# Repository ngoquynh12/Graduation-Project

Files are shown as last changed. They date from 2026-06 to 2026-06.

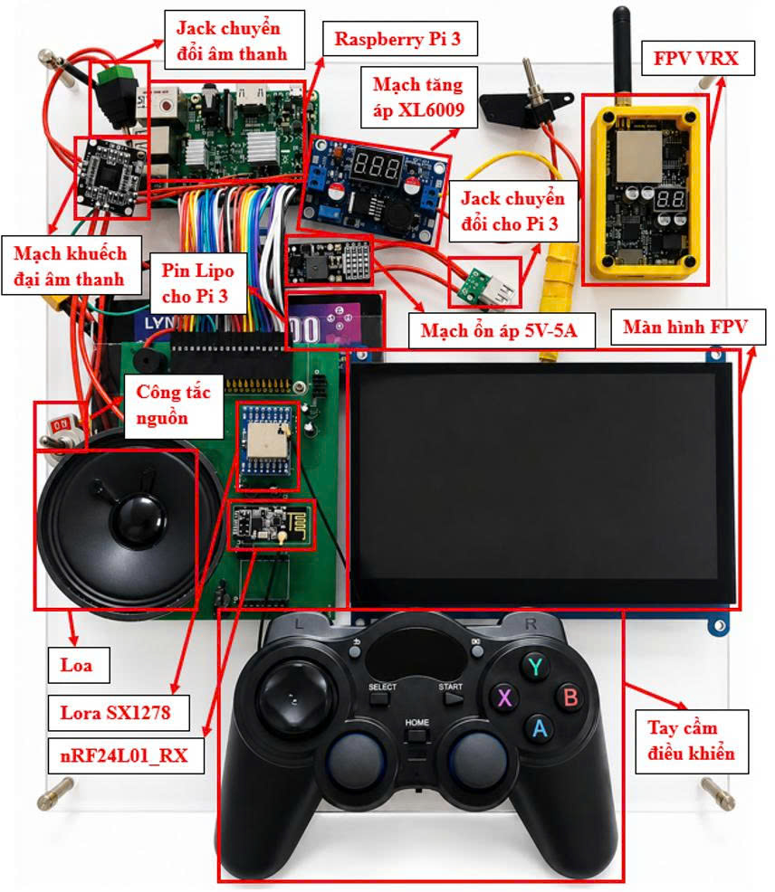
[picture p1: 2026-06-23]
PICTURES/control_station.jpg

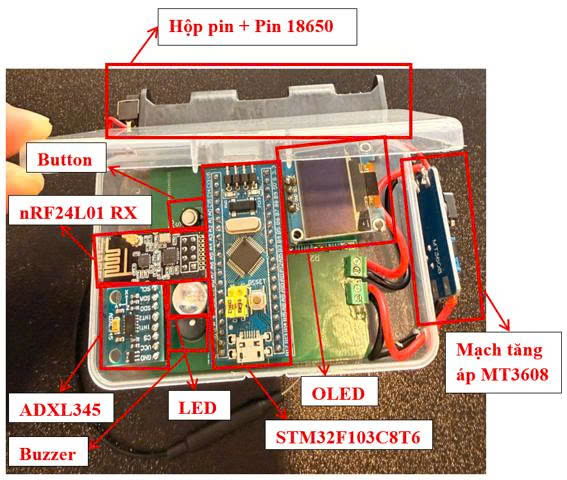
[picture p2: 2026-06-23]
PICTURES/marker.jpg

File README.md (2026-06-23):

# Design and Implementation of an AI-Powered Multi-Sensor Hexapod Robot for Earthquake Search and Rescue

## Overview

This project presents the design and implementation of an AI-powered multi-sensor hexapod robot for earthquake search and rescue applications.

The robot is designed to operate in complex and hazardous environments where direct human access may be dangerous. The system integrates computer vision, audio intelligence, vibration monitoring, wireless communication, FPV monitoring, and autonomous navigation through a multi-sensor fusion architecture.

By combining artificial intelligence, embedded systems, wireless communication, and a six-legged locomotion platform, the robot assists rescue teams in locating potential victims, monitoring disaster areas, and improving situational awareness during emergency operations.

This project was developed as a Graduation Thesis at Ho Chi Minh City University of Technology (HCMUT), Vietnam National University Ho Chi Minh City.

---

## Project Objectives
- Develop a hexapod robot capable of traversing rough terrain.
- Detect humans and animals using AI-based image recognition.
- Detect human and animal sounds using AI-based audio classification.
- Monitor post-earthquake vibrations and aftershocks.
- Support both manual and autonomous operation modes.
- Deploy rescue markers at suspected victim locations.
- Transmit real-time information to a remote control station.
- Provide live FPV video streaming and system monitoring dashboard.

---

## System Architecture

### Robot Platform
- Hexapod structure with 18 DOF.
- Tripod gait locomotion.
- Manual and autonomous navigation modes.
- Obstacle avoidance using distance sensors.

### AI Vision System
- Raspberry Pi 5.
- Raspberry Pi Camera V2.
- YOLOv8 object detection.
- Detection classes: Person, Dog and Cat.

### AI Audio System
- INMP441 I2S Microphone.
- CNN-based audio classification.
- Detection classes: Human voice, Dog bark and Environmental noise.

### Vibration Monitoring
- MPU6050 Accelerometer.
- PGA (Peak Ground Acceleration) calculation.
- MMI (Modified Mercalli Intensity) estimation.
- Aftershock monitoring.

### Wireless Communication
- LoRa SX1278.
- nRF24L01.
- Real-time sensor transmission.
- Remote command and control.

### FPV Monitoring
- FPV Camera.
- 5.8 GHz Video Transmission.
- Real-time video feedback to operator.

### Rescue Marker System
- Marker deployment mechanism.
- Wireless status reporting.
- Rescue state monitoring.

### Web Dashboard
- Real-time sensor monitoring.
- Robot status visualization.
- Marker tracking.
- Alert notifications.

### Ground Control Station
- Real-time dashboard.
- Sensor monitoring.
- Marker tracking.
- Audio alerts.
- Robot telemetry display.

---

## Technologies Used

### Main Hardware
- Raspberry Pi 5 (Main Robot Controller).
- Raspberry Pi 3 (Ground Control Station).
- Raspberry Pi Camera V2.
- INMP441 Microphone.
- MPU6050.
- LoRa SX1278.
- nRF24L01.
- PCA9685 Servo Driver.
- MG946R Servo Motors.
- FPV Camera System.

### Software
- Python.
- YOLOv8.
- TensorFlow / Keras.
- OpenCV.
- Flask.
- HTML / CSS / JavaScript.

### PCB Design
- Altium Designer.

### Mechanical Design
- CAD Modeling.
- 3D Printed Components.

---

## Demo Videos
YouTube Playlist: https://www.youtube.com/playlist?list=PLQ2nYnHPs12wPHYRxYziXRSKi9JFzzbWc

The playlist includes:
- Hexapod locomotion testing.
- Manual control mode.
- Autonomous navigation mode.
- Obstacle avoidance.
- Human detection.
- Audio detection.
- Marker deployment.
- Dashboard monitoring.
- System integration tests.

---

## Results
The developed system successfully demonstrates:
- Stable hexapod locomotion.
- Real-time AI-based human and animal detection.
- AI-based audio recognition.
- Obstacle avoidance capability.
- Aftershock monitoring.
- Wireless communication between robot and control station.
- Rescue marker deployment.
- FPV video transmission.
- Real-time dashboard monitoring.

The integration of AI, embedded systems, wireless communication and multi-sensor fusion improves situational awareness and supports search-and-rescue operations in hazardous environments.

---

## Authors
Ngô Diễm Quỳnh – 2212887

Nguyễn Trọng Tuấn – 2213794

Department of Electronics and Telecommunications Engineering

Ho Chi Minh City University of Technology (HCMUT)

Vietnam National University Ho Chi Minh City

Supervisor: TS. Nguyễn Lý Thiên Trường

---

## License

This repository is published for academic and portfolio purposes.
Please contact the authors before using the materials for commercial applications.

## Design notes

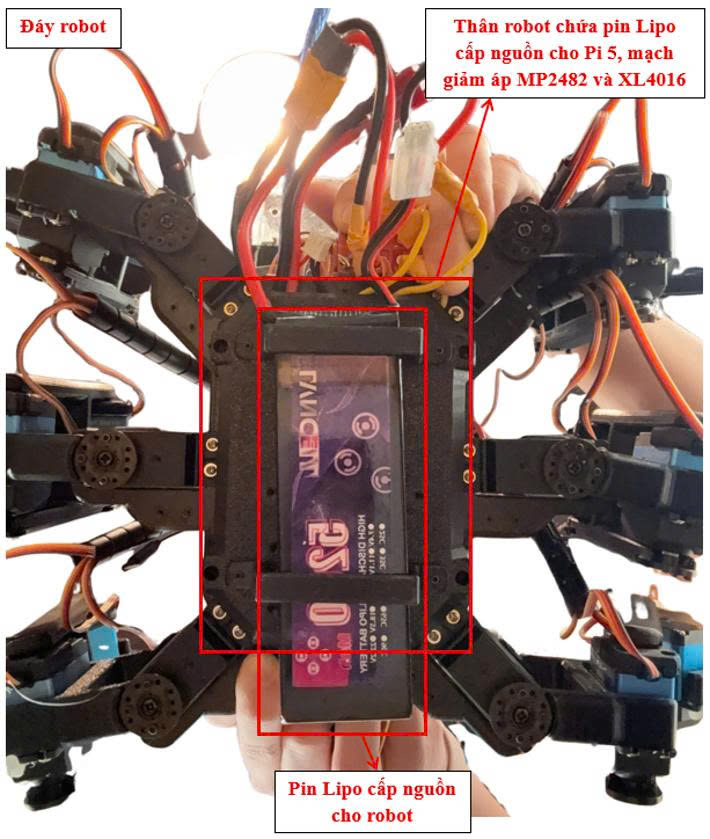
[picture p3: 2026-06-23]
PICTURES/robot_bottom.jpg

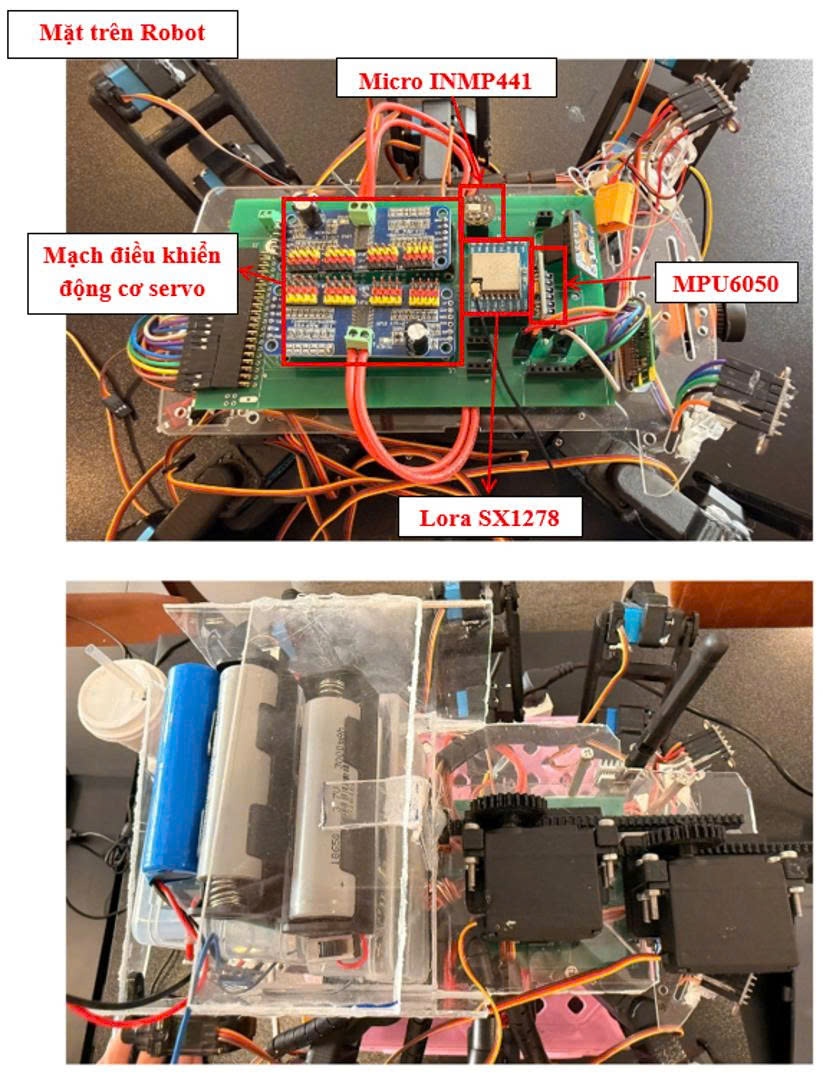
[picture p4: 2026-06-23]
PICTURES/robot_above.jpg

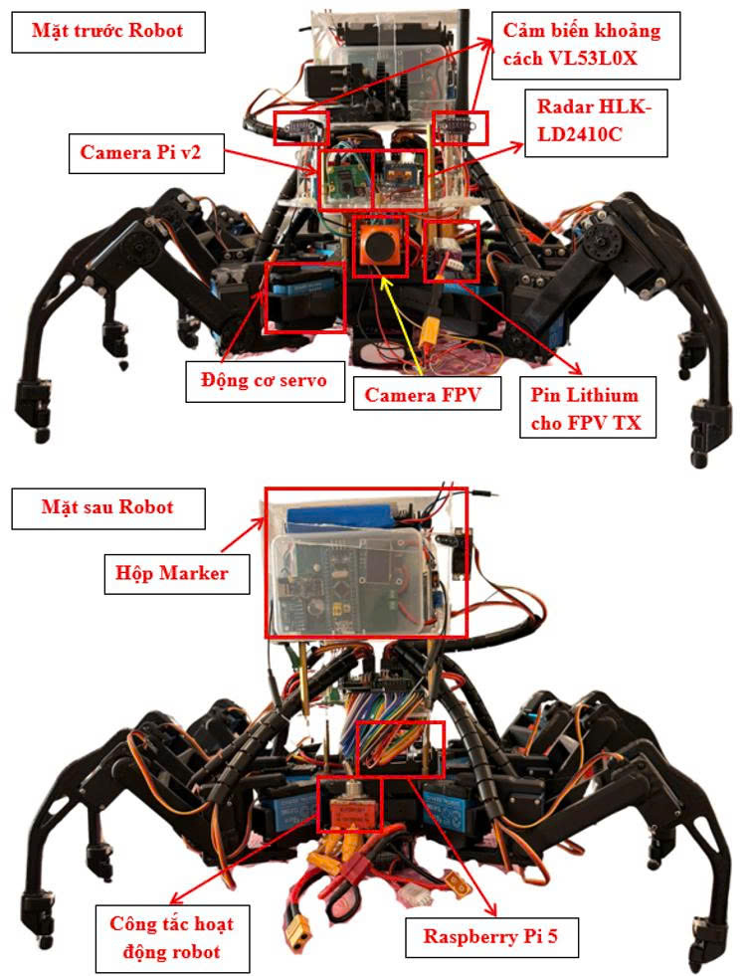
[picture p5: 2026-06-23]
PICTURES/robot_front.jpg

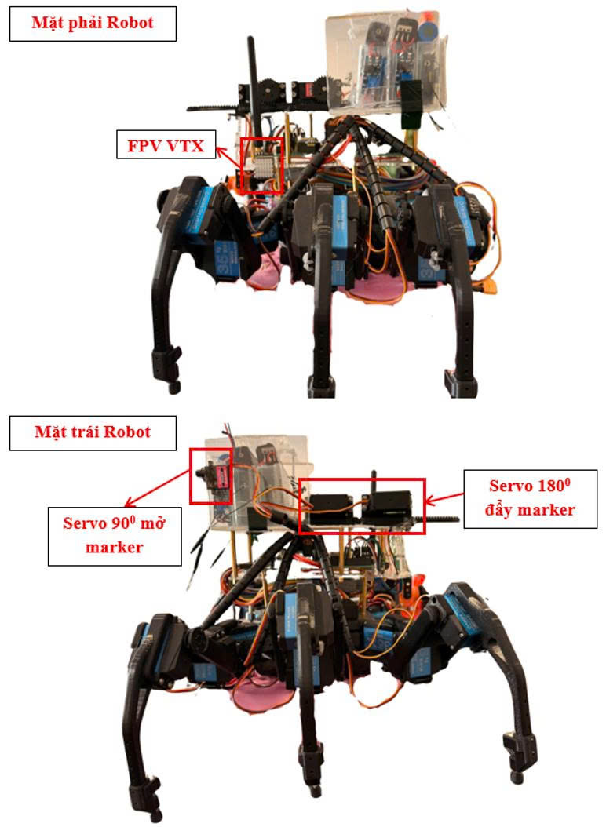
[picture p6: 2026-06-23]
PICTURES/robot_side.jpg

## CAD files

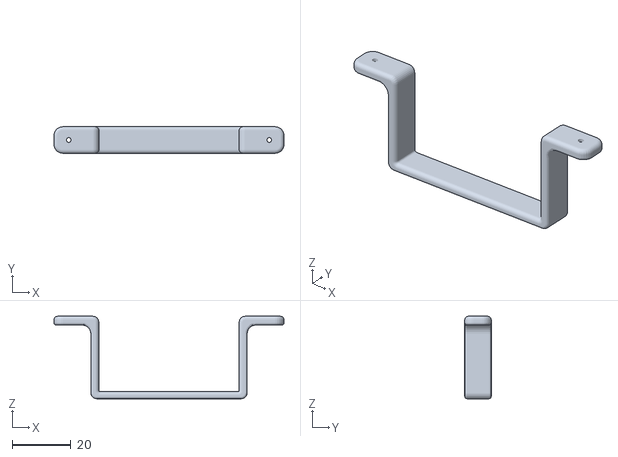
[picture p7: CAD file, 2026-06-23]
Mechanical/battery-bar.stl
78.0 x 9.00 x 28.0

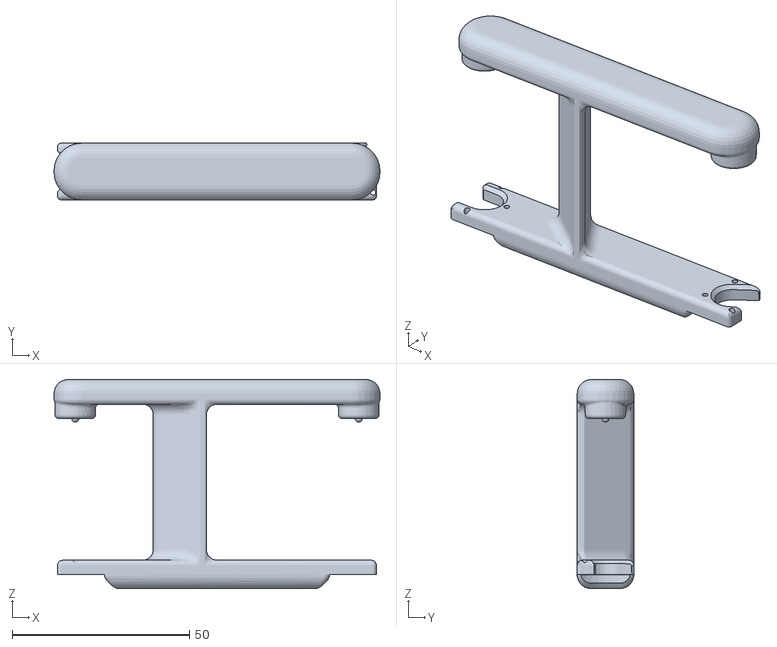
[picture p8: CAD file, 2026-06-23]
Mechanical/right-femur.stl
92.0 x 16.0 x 59.0

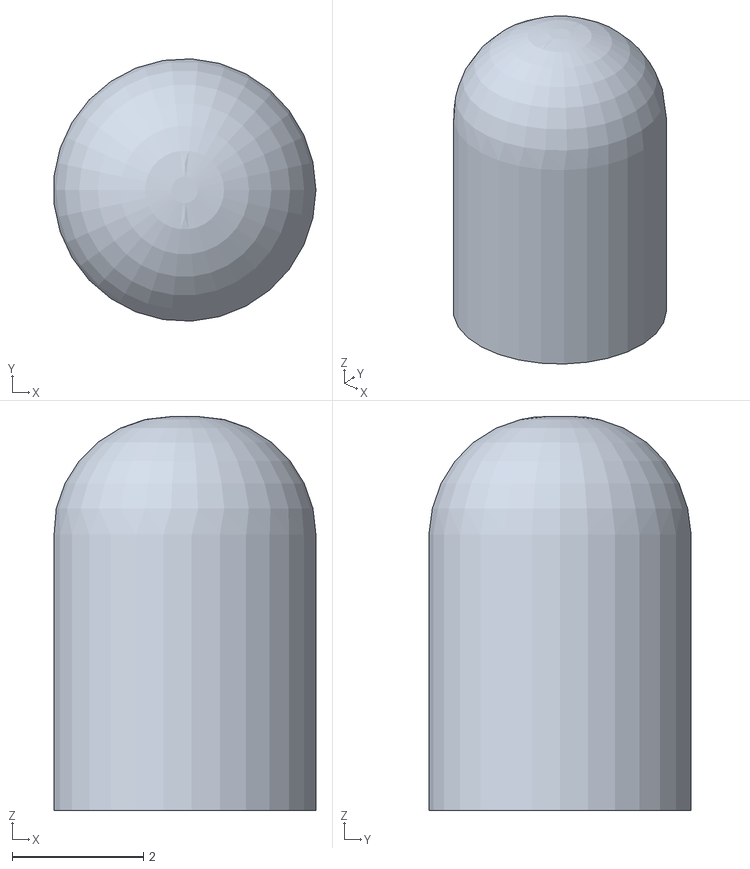
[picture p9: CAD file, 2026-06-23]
Mechanical/limiter.stl
3.99 x 3.99 x 6.00

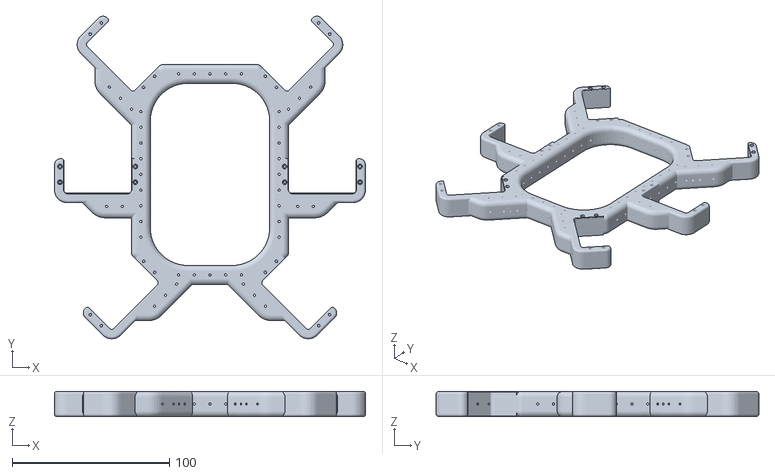
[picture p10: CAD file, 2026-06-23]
Mechanical/frame.stl
198.0 x 205.4 x 16.0

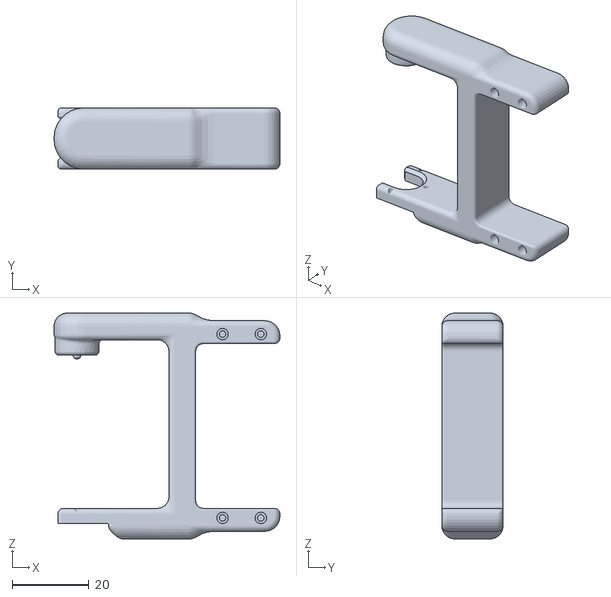
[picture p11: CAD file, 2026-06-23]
Mechanical/right-coxa.stl
59.0 x 16.0 x 59.0

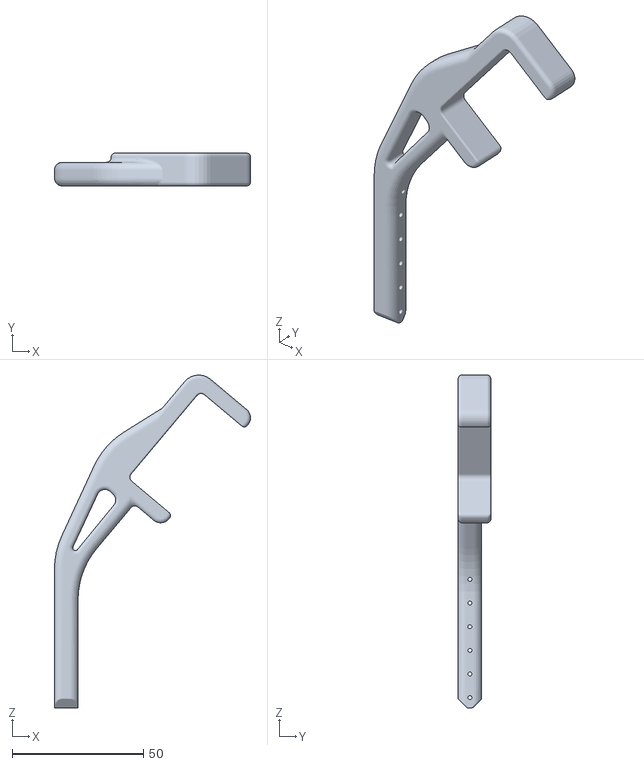
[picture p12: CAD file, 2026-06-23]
Mechanical/right-tibia.stl
74.6 x 12.5 x 126.7

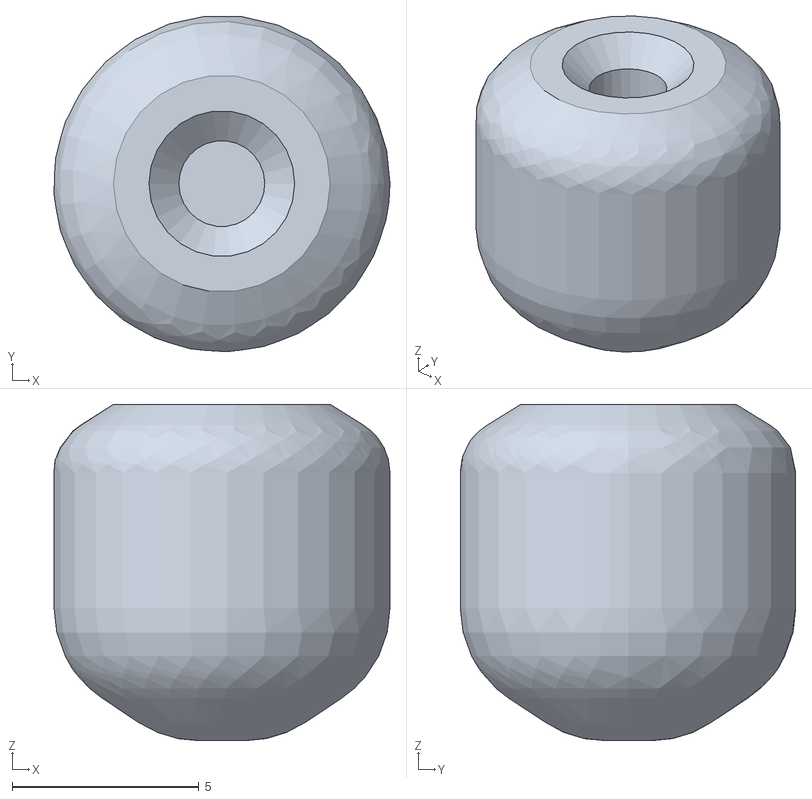
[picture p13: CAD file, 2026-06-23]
Mechanical/tip.stl
8.99 x 8.98 x 9.00

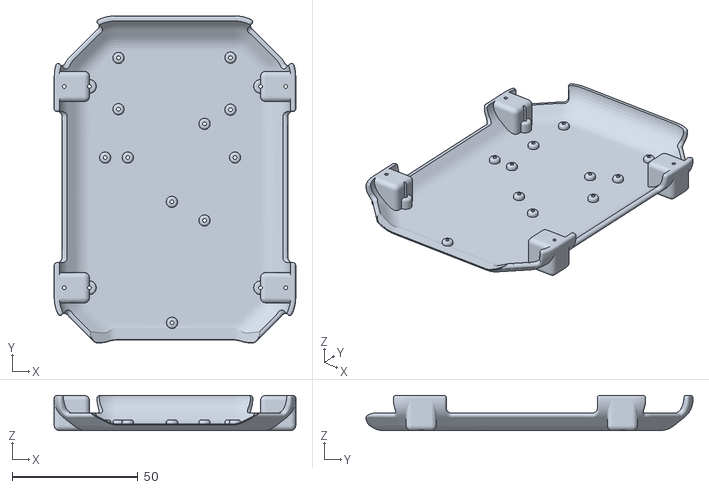
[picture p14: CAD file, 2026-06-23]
Mechanical/bottom-cover.stl
96.0 x 130.0 x 14.0

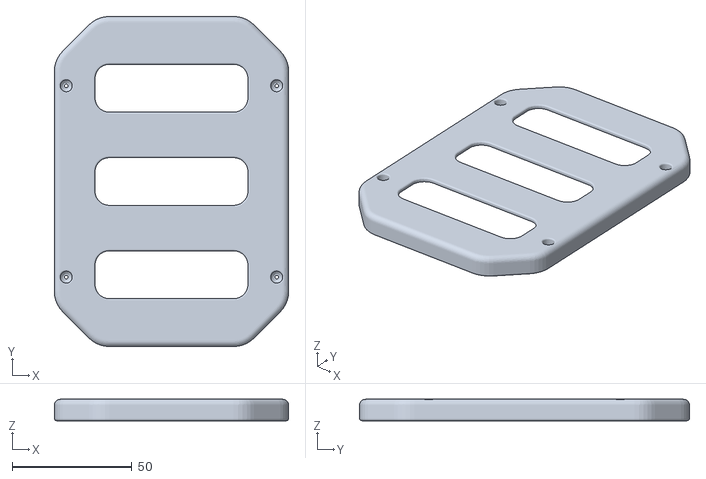
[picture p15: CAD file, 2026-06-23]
Mechanical/top-cover.stl
98.0 x 138.0 x 9.00

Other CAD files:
Mechanical/left-femur.stl
Mechanical/left-tibia.stl
Mechanical/left-coxa.stl

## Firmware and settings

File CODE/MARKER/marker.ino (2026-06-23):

#include <Wire.h>
#include <SPI.h>
#include <RF24.h>
#include <Adafruit_GFX.h>
#include <Adafruit_SSD1306.h>
#include <math.h>

// ================= OLED =================
#define SCREEN_WIDTH 128
#define SCREEN_HEIGHT 64
#define OLED_RESET -1
#define OLED_ADDR 0x3C
Adafruit_SSD1306 display(SCREEN_WIDTH, SCREEN_HEIGHT, &Wire, OLED_RESET);

// ================= ADXL345 (I2C2) =================
#define ADXL_ADDR 0x53
TwoWire I2C_ADXL(PB11, PB10);   // SDA, SCL

// ================= PIN =================
#define LED_PIN       PB0
#define BUZZER_PIN    PB1
#define BUTTON_PIN    PA0
#define BATTERY_PIN   PA2

#define NRF_CE_PIN    PA3
#define NRF_CSN_PIN   PA4

// ================= RF24 =================
RF24 radio(NRF_CE_PIN, NRF_CSN_PIN);
const byte address[6] = "MKR01";

// ================= CONFIG =================
const uint8_t MARKER_ID = 1;

uint8_t markerStatus = 0;

bool ledState = false;
bool radioAvailable = false;
bool lastSendResult = false;
bool adxlAvailable = false;
bool isSleeping = false;

unsigned long previousLedMillis = 0;
unsigned long previousDisplayMillis = 0;
unsigned long previousSendMillis = 0;
unsigned long previousBatteryMillis = 0;
unsigned long lastDebounceTime = 0;
unsigned long bootTime = 0;
unsigned long lastImpactMillis = 0;
unsigned long rescuedTime = 0;

bool lastButtonReading = HIGH;
bool buttonState = HIGH;

const unsigned long ledInterval = 500;
const unsigned long displayInterval = 200;
const unsigned long sendInterval = 1000;
const unsigned long batteryUpdateInterval = 250;
const unsigned long debounceDelay = 50;
const unsigned long impactCooldown = 1500;
const unsigned long rescuedToSleepDelay = 2000;

// double click
int clickCount = 0;
unsigned long lastClickTime = 0;
const unsigned long doubleClickWindow = 400;

// impact detect
int impactCount = 0;
const long impactDeltaThreshold = 520;
const int impactNeedCount = 4;

long baseMagnitude = 0;
bool baseReady = false;

// ================= BATTERY =================
float batteryVoltageShown = -1.0f;
float batteryVoltageRaw = -1.0f;
float batteryVoltageFiltered = -1.0f;

const float batteryCalibrationFactor = 0.001607f;

// chỉnh cho OLED cập nhật tụt áp nhanh hơn
const float batteryTinyDeadband = 0.002f;
const float maxBatteryDropPerUpdate = 0.080f;
const float maxBatteryRisePerUpdate = 0.020f;

// ================= BUZZER =================
const unsigned long buzzerCycle = 2000;

const unsigned long beep1Start = 0;
const unsigned long beep1End   = 150;

const unsigned long beep2Start = 300;
const unsigned long beep2End   = 450;

const unsigned long beep3Start = 600;
const unsigned long beep3End   = 750;

const int freq1 = 2500;
const int freq2 = 3000;
const int freq3 = 3500;

// ================= RF PAYLOAD =================
struct __attribute__((packed)) MarkerPacket {
  uint8_t id;
  uint8_t status;
  float battery;
  uint32_t counter;
};

MarkerPacket packet;
uint32_t packetCounter = 0;

// ================= ADXL DATA =================
int16_t ax = 0, ay = 0, az = 0;

// ================= FORWARD DECLARATIONS =================
void sendMarkerPacket(float batteryVoltage);
void enterSleepMode();
void wakeFromSleep();
bool isBuzzerActive(unsigned long currentMillis);

// ================= HELPER =================
const char* getStatusText(uint8_t st) {
  if (st == 0) return "WAITING";
  if (st == 1) return "NOT RESCUED";
  if (st == 2) return "RESCUED";
  return "UNKNOWN";
}

// ================= ADXL345 =================
void adxlWrite(uint8_t reg, uint8_t value) {
  I2C_ADXL.beginTransmission(ADXL_ADDR);
  I2C_ADXL.write(reg);
  I2C_ADXL.write(value);
  I2C_ADXL.endTransmission();
}

bool adxlReadXYZ(int16_t &x, int16_t &y, int16_t &z) {
  I2C_ADXL.beginTransmission(ADXL_ADDR);
  I2C_ADXL.write(0x32);
  if (I2C_ADXL.endTransmission(false) != 0) return false;

  I2C_ADXL.requestFrom(ADXL_ADDR, 6);
  if (I2C_ADXL.available() < 6) return false;

  x = I2C_ADXL.read() | (I2C_ADXL.read() << 8);
  y = I2C_ADXL.read() | (I2C_ADXL.read() << 8);
  z = I2C_ADXL.read() | (I2C_ADXL.read() << 8);

  return true;
}

bool initADXL345() {
  I2C_ADXL.begin();

  adxlWrite(0x2D, 0x08);
  adxlWrite(0x31, 0x0B);

  delay(20);

  int16_t tx, ty, tz;
  return adxlReadXYZ(tx, ty, tz);
}

void adxlSleep() {
  if (!adxlAvailable) return;
  adxlWrite(0x2D, 0x00);
}

void adxlWake() {
  if (!adxlAvailable) return;
  adxlWrite(0x2D, 0x08);
  delay(10);
}

// ================= BATTERY =================
float readBatteryBlockTrimmedMean(int sampleCount, int adcDelayMs) {
  if (sampleCount < 5) sampleCount = 5;

  int buf[80];
  if (sampleCount > 80) sampleCount = 80;

  for (int i = 0; i < sampleCount; i++) {
    buf[i] = analogRead(BATTERY_PIN);
    delay(adcDelayMs);
  }

  for (int i = 0; i < sampleCount - 1; i++) {
    for (int j = i + 1; j < sampleCount; j++) {
      if (buf[j] < buf[i]) {
        int t = buf[i];
        buf[i] = buf[j];
        buf[j] = t;
      }
    }
  }

  int cut = sampleCount / 5;
  if (cut < 1) cut = 1;
  if (cut * 2 >= sampleCount) cut = 1;

  long sum = 0;
  int count = 0;

  for (int i = cut; i < sampleCount - cut; i++) {
    sum += buf[i];
    count++;
  }

  float rawAvg = sum / (float)count;
  return rawAvg * batteryCalibrationFactor;
}

float readBatteryVoltageStableSnapshot() {
  const int rounds = 7;
  float values[rounds];

  for (int r = 0; r < rounds; r++) {
    values[r] = readBatteryBlockTrimmedMean(25, 2);
    delay(12);
  }

  for (int i = 0; i < rounds - 1; i++) {
    for (int j = i + 1; j < rounds; j++) {
      if (values[j] < values[i]) {
        float t = values[i];
        values[i] = values[j];
        values[j] = t;
      }
    }
  }

  return values[rounds / 2];
}

void initBatteryFilter() {
  float v = readBatteryVoltageStableSnapshot();
  batteryVoltageRaw = v;
  batteryVoltageFiltered = v;
  batteryVoltageShown = v;
}

bool isBuzzerActive(unsigned long currentMillis) {
  if (isSleeping || markerStatus != 1) return false;

  unsigned long phase = currentMillis % buzzerCycle;

  return ((phase >= beep1Start && phase < beep1End) ||
          (phase >= beep2Start && phase < beep2End) ||
          (phase >= beep3Start && phase < beep3End));
}

void updateBatteryShown(unsigned long now) {
  if (batteryVoltageShown < 0.0f) {
    initBatteryFilter();
    return;
  }

  if (now - previousBatteryMillis < batteryUpdateInterval) return;
  previousBatteryMillis = now;

  float newRaw = readBatteryBlockTrimmedMean(15, 1);
  batteryVoltageRaw = newRaw;

  float diff = newRaw - batteryVoltageFiltered;

  if (fabs(diff) <= batteryTinyDeadband) {
    return;
  }

  if (diff > 0) {
    float rise = diff * 0.25f;
    if (rise > maxBatteryRisePerUpdate) rise = maxBatteryRisePerUpdate;
    batteryVoltageFiltered += rise;
  } else {
    float drop = -diff;
    float appliedDrop = drop * 0.70f;
    if (appliedDrop > maxBatteryDropPerUpdate) appliedDrop = maxBatteryDropPerUpdate;
    batteryVoltageFiltered -= appliedDrop;
  }

  batteryVoltageShown = batteryVoltageFiltered;
}

// ================= DISPLAY =================
void updateDisplay(float batteryVoltage, long sumAbs, bool adxlOk) {
  if (isSleeping) return;

  display.clearDisplay();
  display.setTextSize(1);
  display.setTextColor(SSD1306_WHITE);

  display.setCursor(0, 0);
  display.print("Marker: ");
  display.print(MARKER_ID);

  display.setCursor(0, 18);
  display.print("Status: ");
  display.print(getStatusText(markerStatus));

  display.setCursor(0, 30);
  display.print("BAT: ");
  display.print(batteryVoltage, 2);
  display.print(" V");

  display.setCursor(0, 42);
  display.print("RF: ");
  if (!radioAvailable) {
    display.print("Not Found");
  } else {
    display.print(lastSendResult ? "OK" : "NO ACK");
  }

  display.setCursor(0, 54);
  if (!adxlOk) {
    display.print("ADXL: ERROR");
  } else {
    display.print("SUM: ");
    display.print(sumAbs);
  }

  display.display();
}

void showSleepScreen() {
  display.clearDisplay();
  display.setTextSize(1);
  display.setTextColor(SSD1306_WHITE);
  display.setCursor(0, 0);
  display.println("SLEEP MODE");
  display.setCursor(0, 18);
  display.println("Double click");
  display.setCursor(0, 30);
  display.println("to wake");
  display.display();
}

// ================= RF =================
void sendMarkerPacket(float batteryVoltage) {
  if (!radioAvailable || isSleeping) return;

  packet.id = MARKER_ID;
  packet.status = markerStatus;
  packet.battery = batteryVoltage;
  packet.counter = packetCounter++;

  lastSendResult = radio.write(&packet, sizeof(packet));
}

void initNRF24() {
  if (!radio.begin()) {
    radioAvailable = false;
    return;
  }

  radioAvailable = true;
  radio.setChannel(76);
  radio.setPALevel(RF24_PA_LOW);
  radio.setDataRate(RF24_250KBPS);
  radio.setRetries(3, 5);
  radio.openWritingPipe(address);
  radio.stopListening();
}

// ================= ALERT =================
void updateBuzzer(unsigned long currentMillis) {
  if (isSleeping || markerStatus != 1) {
    noTone(BUZZER_PIN);
    return;
  }

  unsigned long phase = currentMillis % buzzerCycle;

  if (phase >= beep1Start && phase < beep1End) {
    tone(BUZZER_PIN, freq1);
  }
  else if (phase >= beep2Start && phase < beep2End) {
    tone(BUZZER_PIN, freq2);
  }
  else if (phase >= beep3Start && phase < beep3End) {
    tone(BUZZER_PIN, freq3);
  }
  else {
    noTone(BUZZER_PIN);
  }
}

void updateLed(unsigned long currentMillis) {
  if (isSleeping) {
    digitalWrite(LED_PIN, LOW);
    ledState = false;
    return;
  }

  if (markerStatus == 1) {
    if (currentMillis - previousLedMillis >= ledInterval) {
      previousLedMillis = currentMillis;
      ledState = !ledState;
      digitalWrite(LED_PIN, ledState);
    }
  } else {
    digitalWrite(LED_PIN, LOW);
    ledState = false;
  }
}

// ================= BUTTON =================
void registerButtonClick() {
  unsigned long now = millis();

  if (now - lastClickTime <= doubleClickWindow) {
    clickCount++;
  } else {
    clickCount = 1;
  }

  lastClickTime = now;
}

void handleButtonRaw() {
  bool reading = digitalRead(BUTTON_PIN);

  if (reading != lastButtonReading) {
    lastDebounceTime = millis();
  }

  if ((millis() - lastDebounceTime) > debounceDelay) {
    if (reading != buttonState) {
      buttonState = reading;

      if (buttonState == LOW) {
        registerButtonClick();
      }
    }
  }

  lastButtonReading = reading;
}

void processButtonClicks() {
  if (clickCount == 0) return;
  if (millis() - lastClickTime <= doubleClickWindow) return;

  if (isSleeping) {
    if (clickCount >= 2) {
      wakeFromSleep();
    }
    clickCount = 0;
    return;
  }

  if (markerStatus == 1) {
    if (clickCount == 1) {
      markerStatus = 2;
      rescuedTime = millis();
      sendMarkerPacket(batteryVoltageShown);
    }
  }

  clickCount = 0;
}

// ================= SLEEP =================
void enterSleepMode() {
  if (isSleeping) return;

  isSleeping = true;

  noTone(BUZZER_PIN);
  digitalWrite(LED_PIN, LOW);
  ledState = false;

  if (radioAvailable) {
    radio.powerDown();
  }

  adxlSleep();

  showSleepScreen();
  delay(800);

  display.ssd1306_command(SSD1306_DISPLAYOFF);
}

void wakeFromSleep() {
  if (!isSleeping) return;

  isSleeping = false;

  display.ssd1306_command(SSD1306_DISPLAYON);
  delay(50);

  if (radioAvailable) {
    radio.powerUp();
    delay(10);
    radio.stopListening();
  }

  adxlWake();

  markerStatus = 0;
  bootTime = millis();
  lastImpactMillis = 0;
  clickCount = 0;
  impactCount = 0;
  baseReady = false;
  baseMagnitude = 0;

  initBatteryFilter();

  sendMarkerPacket(batteryVoltageShown);
  updateDisplay(batteryVoltageShown, 0, adxlAvailable);
}

// ================= DROP DETECTION =================
long calcMagnitudeAbs(int16_t x, int16_t y, int16_t z) {
  return abs(x) + abs(y) + abs(z);
}

void updateDropDetection(unsigned long now, bool adxlOk, long sumAbs) {
  if (isSleeping) return;
  if (!adxlOk) return;

  // bỏ qua lúc mới bật nguồn
  if (now - bootTime < 2500) return;

  // chỉ phát hiện khi đang WAITING
  if (markerStatus != 0) return;

  // tránh kích hoạt liên tục
  if (now - lastImpactMillis < impactCooldown) return;

  // tạo giá trị nền ban đầu theo tư thế thực tế của marker
  if (!baseReady) {
    baseMagnitude = sumAbs;
    baseReady = true;
    impactCount = 0;
    return;
  }

  long delta = labs(sumAbs - baseMagnitude);

  // cập nhật nền chậm để thích nghi với tư thế nằm dọc/ngang
  baseMagnitude = (baseMagnitude * 95 + sumAbs * 5) / 100;

  if (delta > impactDeltaThreshold) {
    impactCount++;
  } else {
    if (impactCount > 0) impactCount--;
  }

  if (impactCount >= impactNeedCount) {
    markerStatus = 1;
    lastImpactMillis = now;
    impactCount = 0;

    sendMarkerPacket(batteryVoltageShown);
  }
}

// ================= SETUP =================
void setup() {
  pinMode(LED_PIN, OUTPUT);
  pinMode(BUZZER_PIN, OUTPUT);
  pinMode(BUTTON_PIN, INPUT_PULLUP);

  digitalWrite(LED_PIN, LOW);
  noTone(BUZZER_PIN);

  analogReadResolution(12);

  Wire.begin();

  if (!display.begin(SSD1306_SWITCHCAPVCC, OLED_ADDR)) {
    while (1);
  }

  display.clearDisplay();
  display.setTextSize(1);
  display.setTextColor(SSD1306_WHITE);
  display.setCursor(0, 0);
  display.println("Init system...");
  display.display();

  initNRF24();
  adxlAvailable = initADXL345();

  markerStatus = 0;
  isSleeping = false;
  bootTime = millis();
  rescuedTime = 0;
  impactCount = 0;

  initBatteryFilter();
  delay((MARKER_ID - 1) * 300);
  previousSendMillis = millis();

  sendMarkerPacket(batteryVoltageShown);

  long sumAbs = 0;
  if (adxlAvailable && adxlReadXYZ(ax, ay, az)) {
    sumAbs = abs(ax) + abs(ay) + abs(az);
  }

  updateDisplay(batteryVoltageShown, sumAbs, adxlAvailable);
}

// ================= LOOP =================
void loop() {
  unsigned long currentMillis = millis();

  handleButtonRaw();
  processButtonClicks();

  if (isSleeping) {
    delay(30);
    return;
  }

  bool adxlOk = false;
  long sumAbs = 0;

  if (adxlAvailable) {
    adxlOk = adxlReadXYZ(ax, ay, az);
    if (adxlOk) {
      sumAbs = abs(ax) + abs(ay) + abs(az);
      updateDropDetection(currentMillis, adxlOk, sumAbs);
    }
  }

  updateLed(currentMillis);
  updateBuzzer(currentMillis);

  updateBatteryShown(currentMillis);

  if (markerStatus == 2 && rescuedTime > 0) {
    if (currentMillis - rescuedTime >= rescuedToSleepDelay) {
      enterSleepMode();
      delay(30);
      return;
    }
  }

  if (currentMillis - previousSendMillis >= sendInterval) {
    previousSendMillis = currentMillis;
    sendMarkerPacket(batteryVoltageShown);
  }

  if (currentMillis - previousDisplayMillis >= displayInterval) {
    previousDisplayMillis = currentMillis;
    updateDisplay(batteryVoltageShown, sumAbs, adxlOk);
  }

  delay(10);
}

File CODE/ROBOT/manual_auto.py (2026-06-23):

#MANUAL_AUTO
import sys
import time
import signal
import threading
from dataclasses import dataclass
import random
import os
import json
from xxlimited import new
#from turtle import left, right

import board
import busio
import digitalio
import RPi.GPIO as GPIO
from adafruit_pca9685 import PCA9685
import adafruit_vl53l0x

# =========================================================
# LORA IMPORT
# =========================================================
sys.path.append("/home/pi/human_sound_model/pySX127x")
from SX127x.board_config import BOARD
from SX127x.LoRa import LoRa
from SX127x.constants import MODE

SENSOR_FILE = "/tmp/full_sensor.json"
SENSOR_REQ_FILE = "/tmp/sensor_request.json"

last_json_sent = ""
last_json_send_time = 0
JSON_SEND_INTERVAL = 1.0

AUTO_SCAN_INTERVAL = 9999
AUTO_STABLE_WAIT = 0.35
AUTO_SNAPSHOT_WAIT = 0.15
person_detect_count = 0
PERSON_CONFIRM_COUNT = 5
person_clear_count = 0
PERSON_CLEAR_COUNT = 10
marker_detect_armed = True
last_auto_scan_time = 0
auto_scan_busy = False

# =========================================================
# LORA GPIO CONFIG
# =========================================================
RST_PIN = 22
DIO0_PIN = 4
FREQ = 433.0

LORA_TIMEOUT = 2.0
last_lora_time = 0

def custom_setup():
    GPIO.setmode(GPIO.BCM)
    GPIO.setwarnings(False)

    GPIO.setup(RST_PIN, GPIO.OUT)
    GPIO.output(RST_PIN, 1)

    GPIO.setup(DIO0_PIN, GPIO.IN, pull_up_down=GPIO.PUD_DOWN)

def custom_teardown():
    try:
        GPIO.cleanup()
    except Exception:
        pass

    try:
        if BOARD.spi is not None:
            BOARD.spi.close()
            BOARD.spi = None
    except Exception:
        pass
    GPIO.cleanup()

BOARD.setup = custom_setup
BOARD.teardown = custom_teardown
BOARD.add_event_detect = lambda *args, **kwargs: None
BOARD.add_events = lambda *args, **kwargs: None

# =========================================================
# PCA9685
# =========================================================
I2C_FREQ = 100000
PCA_LEFT_ADDR = 0x40
PCA_RIGHT_ADDR = 0x60

# =========================================================
# VL53 CONFIG
# =========================================================
XSHUT_LEFT_PIN = board.D17
XSHUT_RIGHT_PIN = board.D27

MAX_DISTANCE_CM = 60
CLEAR_CM = 35
LEFT_OBSTACLE_CM = 15
RIGHT_OBSTACLE_CM = 20
DANGER_CM = 10
CONFIRM_COUNT = 2
DIFF_BALANCE_CM = 3

near_count_l = 0
near_count_r = 0

# =========================================================
# OFFSET
# =========================================================
offL = [
    0, 0, 0, 0,
    0, 0, 0, 0,
    0, 0, 0, 0,
    0, 0, 0, 0
]

offR = [
    -5, 0, 0, 0,
    0, 0, -5, 0,
    0, 0, 0, 0,
    0, 0, 0, 0
]

# =========================================================
# LEFT CHANNELS
# =========================================================
LF_COXA  = 15
LF_FEMUR = 14
LF_TIBIA = 13
LM_COXA  = 12
LM_FEMUR = 11
LM_TIBIA = 10
LR_COXA  = 9
LR_FEMUR = 8
LR_TIBIA = 7

# =========================================================
# RIGHT CHANNELS
# =========================================================
RF_COXA  = 0
RF_FEMUR = 1
RF_TIBIA = 2
RM_COXA  = 3
RM_FEMUR = 4
RM_TIBIA = 5
RR_COXA  = 6
RR_FEMUR = 7
RR_TIBIA = 8

# =========================================================
# THÔNG SỐ
# =========================================================
MID = 300

# lift khi di chuyển
L_UP_FEMUR = 420
L_UP_TIBIA = 420
R_UP_FEMUR = 185
R_UP_TIBIA = 185
RF_UP_FEMUR = 170
RF_UP_TIBIA = 170
# LOW pose đã test
L_LOW_FEMUR = 355
L_LOW_TIBIA = 265
R_LOW_FEMUR = 245
R_LOW_TIBIA = 335

# bước tiến/lùi
L_FWD = 350
L_BWD = 250
R_FWD = 250
R_BWD = 350

# quay trái/phải
L_TURN_FWD = 340
L_TURN_BWD = 260
R_TURN_FWD = 260
R_TURN_BWD = 340

# =========================================================
# SPEED
# =========================================================
GAIT_STEP_DELAY = 0.003
GAIT_STEP_SIZE = 4
GAIT_PHASE_DELAY = 0.002

TRANSITION_STEP_DELAY = 0.03
TRANSITION_STEP_SIZE = 2

STAND_HOLD = 0.0

# =========================================================
# ROBOT STATE
# =========================================================
ROBOT_BOOTING  = 0
ROBOT_LOW      = 1
ROBOT_STANDING = 2
ROBOT_MOVING   = 3

DIR_FORWARD = 0
DIR_BACKWARD = 1
DIR_TURN_LEFT = 2
DIR_TURN_RIGHT = 3

# =========================================================
# GLOBALS
# =========================================================
robotState = ROBOT_BOOTING
current_cmd = "IDLE"
running = True

pose_lock = threading.Lock()
motion_enabled = False
busy_transition = False

MODE_MANUAL = "MANUAL"
MODE_AUTO = "AUTO"

robot_mode = MODE_MANUAL
vl_left = None
vl_right = None

# =========================================================
# MARKER
# =========================================================
marker_count = 0
marker_busy = False
robot_locked = False

MARKER_PUSH_SERVO_1 = 9
MARKER_PUSH_SERVO_2 = 10
MARKER_DOOR_SERVO   = 11

SERVOMIN = 120
SERVOMAX = 600

PUSH1_HOME = 10
PUSH1_HALF = 80
PUSH1_OUT  = 155

PUSH2_HOME  = 10
PUSH2_SMALL = 80
PUSH2_OUT   = 155

DOOR_CLOSE = 72
DOOR_OPEN  = 0

# =========================================================
# STUCK DETECT + ALERT
# =========================================================
hard_block_count = 0
HARD_BLOCK_CONFIRM = 6
HARD_BLOCK_CM = 20

STUCK_TIME = 3.0
STUCK_DELTA_CM = 2.5
MAX_STUCK_RETRY = 2

stuck_start_time = None
last_stuck_left = None
last_stuck_right = None
stuck_retry_count = 0

lora_radio = None
lora_lock = threading.Lock()
last_alert_time = 0
ALERT_COOLDOWN = 5.0

# =========================================================
# I2C + PCA INIT
# =========================================================
i2c = busio.I2C(board.SCL, board.SDA, frequency=I2C_FREQ)
pcaL = PCA9685(i2c, address=PCA_LEFT_ADDR)
pcaR = PCA9685(i2c, address=PCA_RIGHT_ADDR)
pcaL.frequency = 50
pcaR.frequency = 50

# =========================================================
# POSE DATA
# =========================================================
@dataclass
class RobotPose:
    lfC: int = MID
    lfF: int = L_LOW_FEMUR
    lfT: int = L_LOW_TIBIA

    lmC: int = MID
    lmF: int = L_LOW_FEMUR
    lmT: int = L_LOW_TIBIA

    lrC: int = MID
    lrF: int = L_LOW_FEMUR
    lrT: int = L_LOW_TIBIA

    rfC: int = MID
    rfF: int = R_LOW_FEMUR
    rfT: int = R_LOW_TIBIA

    rmC: int = MID
    rmF: int = R_LOW_FEMUR
    rmT: int = R_LOW_TIBIA

    rrC: int = MID
    rrF: int = R_LOW_FEMUR
    rrT: int = R_LOW_TIBIA

pose = RobotPose()

# =========================================================
# LOW LEVEL PWM
# =========================================================
def pulse_to_duty_cycle(pulse: int) -> int:
    pulse = max(0, min(4095, pulse))
    return pulse << 4

def set_pwm(pca: PCA9685, ch: int, pulse: int):
    pca.channels[ch].duty_cycle = pulse_to_duty_cycle(pulse)

def setL(ch: int, pulse: int):
    set_pwm(pcaL, ch, pulse + offL[ch])

def setR(ch: int, pulse: int):
    set_pwm(pcaR, ch, pulse + offR[ch])
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

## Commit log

2026-06-23 Reorganize project structure
    [battery-bar.stl, bottom-cover.stl, distance_log.csv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]
2026-06-23 Add project images and PCB design files
    [1_Controller.PrjPcb, 1_Controller.SchDoc, 8FX1-254MM.SchLib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]
